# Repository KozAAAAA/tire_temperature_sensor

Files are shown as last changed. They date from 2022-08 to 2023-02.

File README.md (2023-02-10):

# Tire Temperature Sensor v2.0

**TTS** (Tire Temperature Sensor) is a PCB designed to measure temperature quickly, at a distance, and without the need to touch the wheels. The 4x16 pixel IR camera is used to obtain the data. It communicates with the STM microprocessor via the I2C protocol. Data is then averaged out to a 1x8 array of unsigned ints and sent with the CAN Transceiver to the car’s CAN network. This array can be then read off of the telemetry system implemented in the PM-08 racing car.

<p align="center">
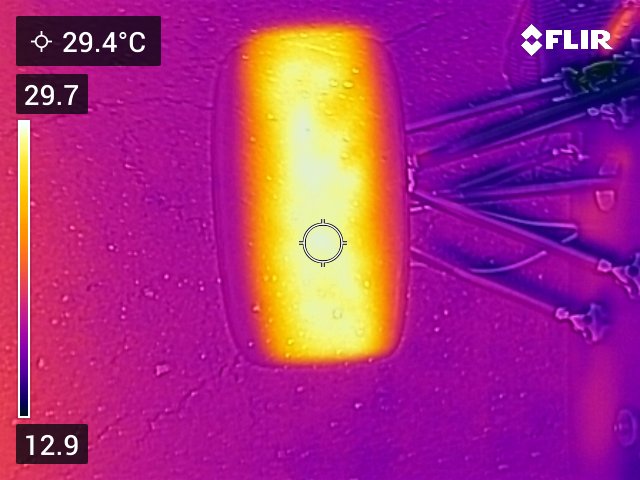
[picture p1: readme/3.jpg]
  
</p>

<p align="center">
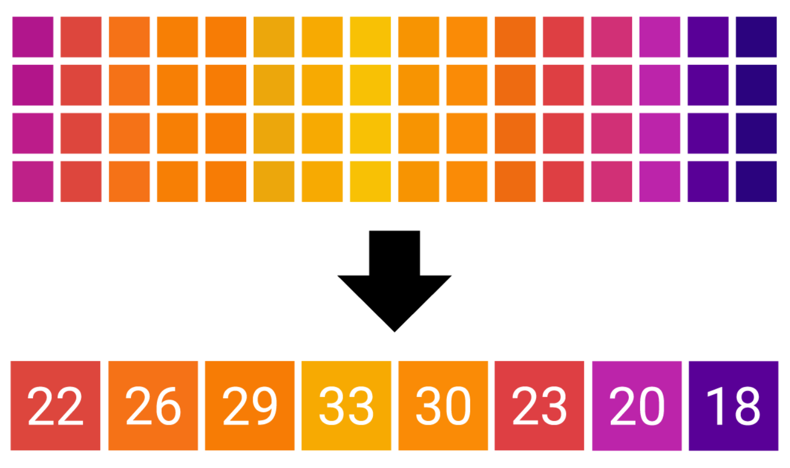
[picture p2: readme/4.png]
  
</p>

## Applications

While driving, a tire heats up. Heat dissipates differently across its surface and its rate changes depending on many factors (E.g. weather conditions or reoccurring acceleration). As a tire has its maximal temperature, exceeding this value may weaken its structural strength and cause its destruction in the worst-case scenario. This IR Camera PCB makes it possible to monitor a tire across its whole surface and prevent any damage associated with the temperature. As TTS monitors every wheel out of 4, our crew can easily detect if tires wear unevenly or excessively. Tire temperature patterns inform whether the car is properly calibrated, as the out-of-tune suspension causes tires to heat up significantly faster. This may result in grip loss in these areas.

## Core features

* 4x16 pixel MLX90621 thermal camera
* STM32L4P5RET
* 24V to 3.3V buck converter
* 3.3V to 2.6V LDO
* 3.3V CAN transceiver
* Overcurrent and reverse polarity protection
* Status LEDs

## PCB

<p align="center">
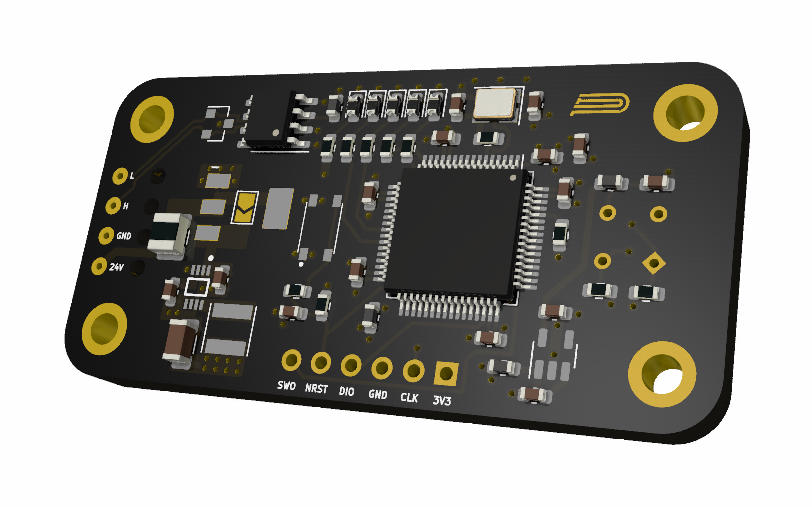
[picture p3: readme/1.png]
  
</p>
<p align="center">
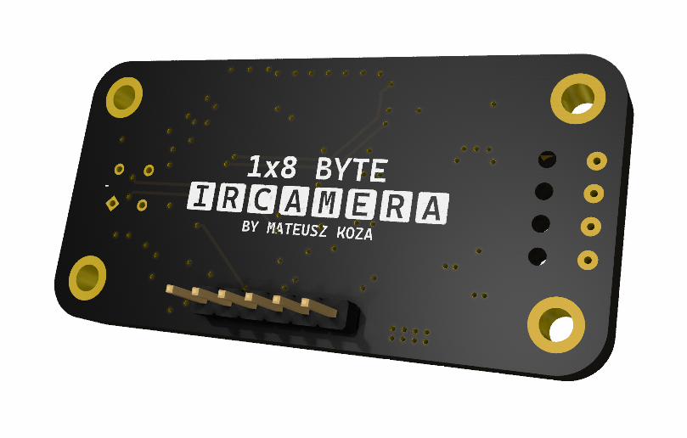
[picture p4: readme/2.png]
  
</p>

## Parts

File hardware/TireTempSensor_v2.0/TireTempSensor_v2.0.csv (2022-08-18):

Source: | /home/mateusz/Desktop/TireTempSensor_v2.0/hardware/TireTempSensor_v2.0/TireTempSensor_v2.0.kicad_sch
Date: | Wed 17 Aug 2022 20:23:14 CEST
Tool: | Eeschema 6.0.7-f9a2dced07~116~ubuntu20.04.1
Generator: | /usr/share/kicad/plugins/bom_csv_grouped_by_value_with_fp.py
Component Count: | 54
Ref | Qnty | Value | Cmp name | Footprint | Description | Vendor
C1, | 1 | 4u7 | C_Small | Capacitor_SMD:C_0603_1608Metric | Unpolarized capacitor, small symbol
C2, C3, C4, C5, C6, C7, C11, C14, C15, C17, | 10 | 100n | C | Capacitor_SMD:C_0603_1608Metric | Unpolarized capacitor
C9, C10, | 2 | 8p | C_Small | Capacitor_SMD:C_0603_1608Metric | Unpolarized capacitor, small symbol
C12, C13, | 2 | 1u | C | Capacitor_SMD:C_0603_1608Metric | Unpolarized capacitor
C16, | 1 | 10u | C | Capacitor_SMD:C_1206_3216Metric | Unpolarized capacitor
D1, | 1 | PESD2CAN,215 | NUP2105L | Package_TO_SOT_SMD:SOT-23 | Dual Line CAN Bus Protector, 24Vrwm
D2, D6, | 2 | RED | D_Small | Diode_SMD:D_0603_1608Metric | Diode, small symbol
D3, D4, | 2 | YELLOW | D_Small | Diode_SMD:D_0603_1608Metric | Diode, small symbol
D5, | 1 | GREEN | D_Small | Diode_SMD:D_0603_1608Metric | Diode, small symbol
F1, | 1 | 200mA | Polyfuse | Capacitor_SMD:C_1206_3216Metric | Resettable fuse, polymeric positive temperature coefficient
FB1, FB2, FB3, FB4, | 4 | 60R@100MHz | FerriteBead_Small | Inductor_SMD:L_0603_1608Metric | Ferrite bead, small symbol
H1, H2, H3, H4, | 4 | Mounting_Pad | MountingHole_Pad | MountingHole:MountingHole_2.7mm_M2.5_ISO14580_Pad | Mounting Hole with connection
IC1, | 1 | MAX15462AATA+ | MAX15462AATA+ | BuckSyncLib:SON50P300X200X80-8N | IC REG BUCK 3.3V 300MA 8TDFN
IC2, | 1 | MLX90621ESF-BAB-000-SP | MLX90621ESF-BAB-000-SP | IRSensor:MLX90621ESFBAB000SP | Board Mount Temperature Sensors 16X4 thermal array sensor, 3Volt, 60deg total FOV
J1, | 1 | SWD_01x06 | Conn_01x06 | Connector_PinHeader_2.54mm:PinHeader_1x06_P2.54mm_Vertical | Generic connector, single row, 01x06, script generated (kicad-library-utils/schlib/autogen/connector/)
J2, | 1 | CAN_01x04 | Conn_01x04 | Connector_Wire:SolderWire-0.1sqmm_1x04_P3.6mm_D0.4mm_OD1mm_Relief | Generic connector, single row, 01x04, script generated (kicad-library-utils/schlib/autogen/connector/)
JP1, | 1 | SolderJumper_2_Open | SolderJumper_2_Open | Jumper:SolderJumper-2_P1.3mm_Open_TrianglePad1.0x1.5mm | Solder Jumper, 2-pole, open
L1, | 1 | 33μH | L | Inductor_SMD:L_Vishay_IFSC-1515AH_4x4x1.8mm | Inductor
Q1, | 1 | FQT3P20TF | Q_PMOS_DSG | Mosfet:SOT-223-4-NFET | P-MOSFET transistor, drain/source/gate
R1, | 1 | 100k | R_Small_US | Resistor_SMD:R_0603_1608Metric | Resistor, small US symbol
R2, | 1 | 47 | R_Small_US | Resistor_SMD:R_0603_1608Metric | Resistor, small US symbol
R3, | 1 | 1k | R_Small_US | Resistor_SMD:R_0603_1608Metric | Resistor, small US symbol
R4, R7, R8, R9, R10, | 5 | 1k5 | R_Small_US | Resistor_SMD:R_0603_1608Metric | Resistor, small US symbol
R5, R6, | 2 | 4k7 | R_US | Resistor_SMD:R_0603_1608Metric | Resistor, US symbol
R11, | 1 | 10k | R_Small_US | Resistor_SMD:R_0603_1608Metric | Resistor, small US symbol
SW1, | 1 | RESET | SW_MEC_5G | Button:PTS815SJK250SMTRLFS | MEC 5G single pole normally-open tactile switch
U1, | 1 | STM32L4P5RET6 | STM32L4P5RET6 | Package_QFP:LQFP-64_10x10mm_P0.5mm
U2, | 1 | MIC5306-2.6YD5-TR | AP2112K-3.3 | Package_TO_SOT_SMD:SOT-23-5 | 600mA low dropout linear regulator, with enable pin, 3.8V-6V input voltage range, 3.3V fixed positive output, SOT-23-5
U3, | 1 | SN65HVD232 | SN65HVD232 | Package_SO:SOIC-8_3.9x4.9mm_P1.27mm | CAN Bus Transceivers, 3.3V, 1Mbps, SOIC-8
Y1, | 1 | 16MGHz | Crystal_GND24_Small | Crystal:Crystal_SMD_SeikoEpson_TSX3225-4Pin_3.2x2.5mm | Four pin crystal, GND on pins 2 and 4, small symbol

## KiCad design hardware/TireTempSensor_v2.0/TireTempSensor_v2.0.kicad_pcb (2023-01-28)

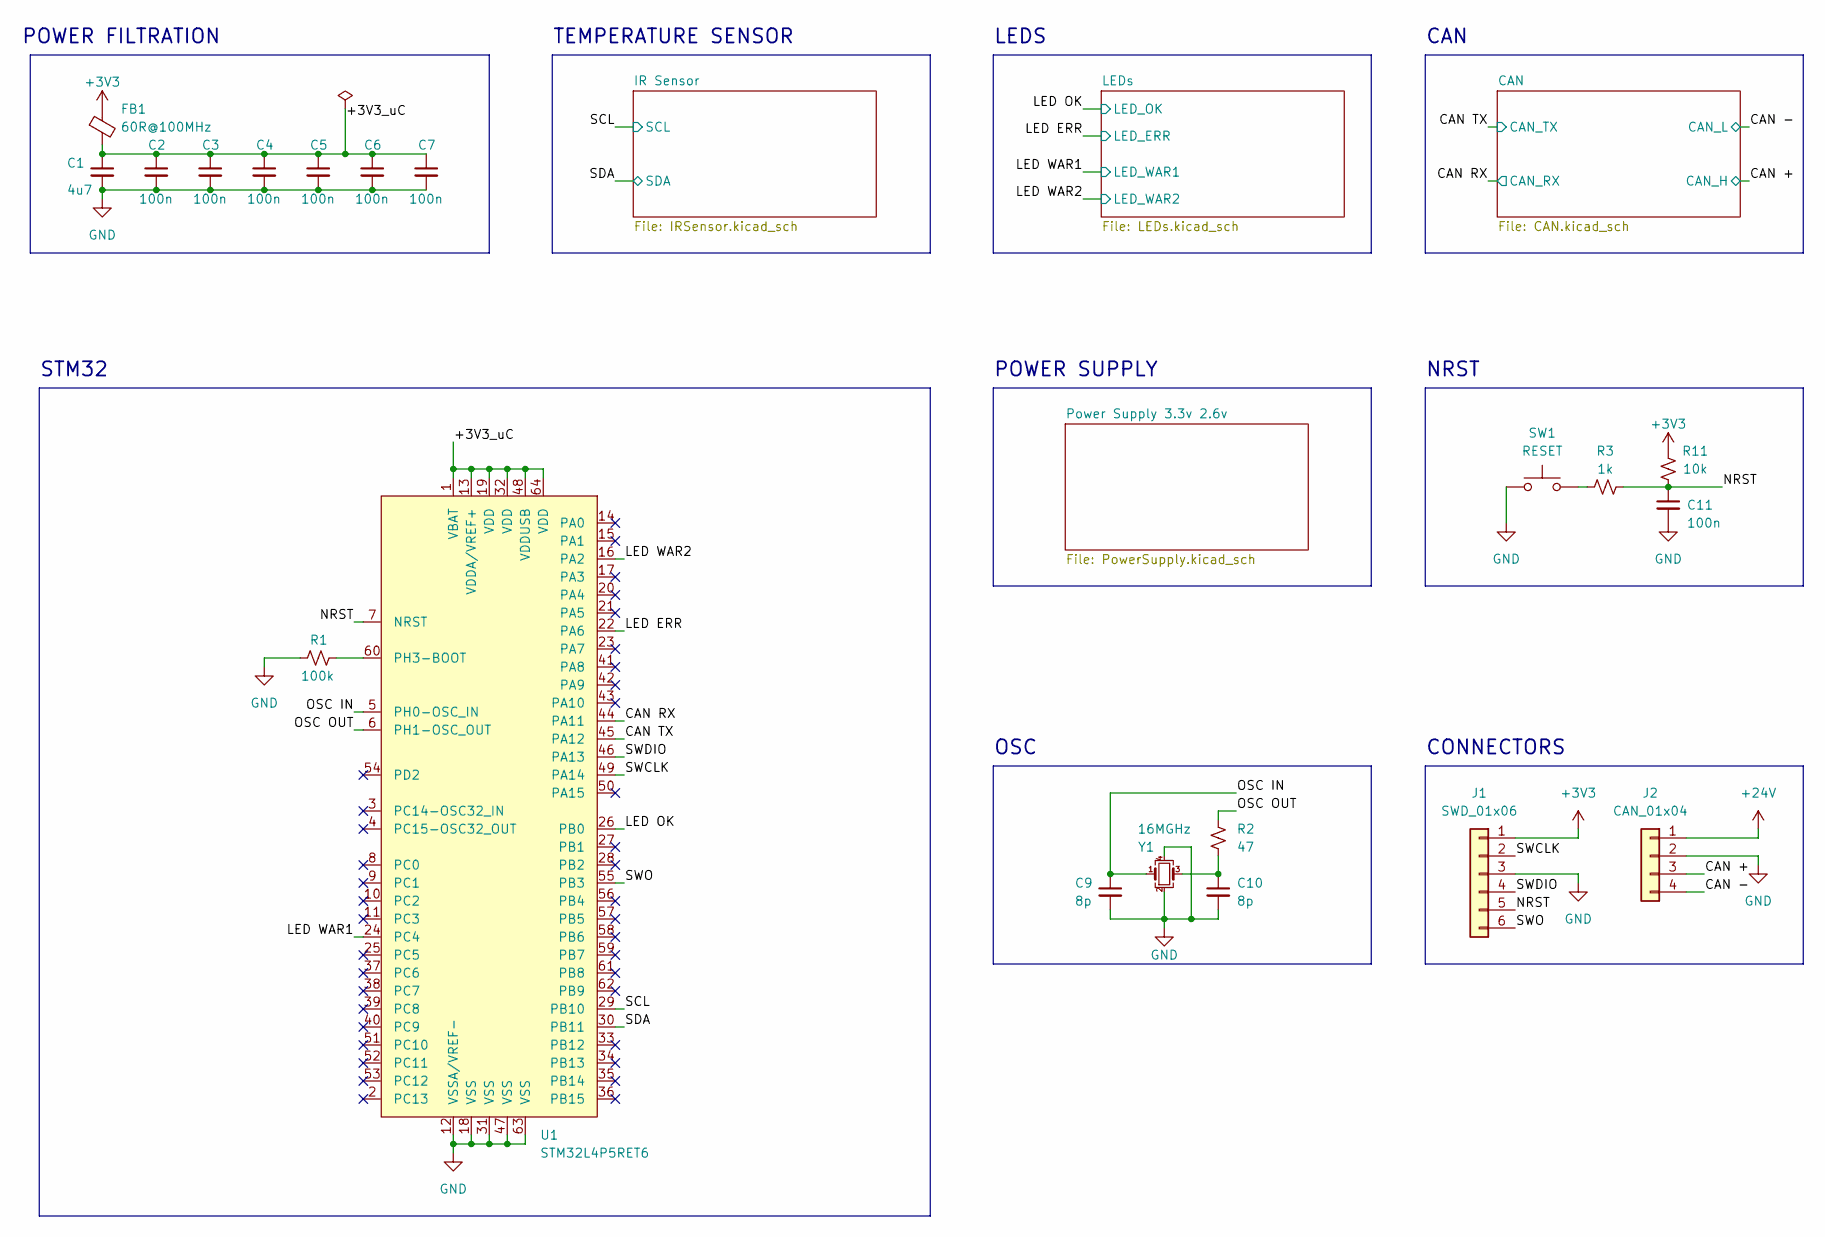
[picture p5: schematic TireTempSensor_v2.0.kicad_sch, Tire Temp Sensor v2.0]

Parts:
C1: 4u7; C_0603_1608Metric
C2, C3, C4, C5, C6, C7, C11: 100n; C_0603_1608Metric
C9, C10: 8p; C_0603_1608Metric
FB1: 60R@100MHz; L_0603_1608Metric
J1: SWD_01x06; PinHeader_1x06_P2.54mm_Vertical
J2: CAN_01x04; SolderWire-0.1sqmm_1x04_P3.6mm_D0.4mm_OD1mm_Relief
R1: 100k; R_0603_1608Metric
R2: 47; R_0603_1608Metric
R3: 1k; R_0603_1608Metric
R11: 10k; R_0603_1608Metric
SW1: RESET; PTS815SJK250SMTRLFS
U1: STM32L4P5RET6; LQFP-64_10x10mm_P0.5mm
Y1: 16MGHz; Crystal_SMD_SeikoEpson_TSX3225-4Pin_3.2x2.5mm

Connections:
+3V3: FB1.1, J1.1, R11.2; also elsewhere on the board
+24V: J2.1; also elsewhere on the board
/+3V3_uC: C1.1, C2.1, C3.1, C4.1, C5.1, C6.1, C7.1, FB1.2, U1.1 (VBAT), U1.13 (VDDA/VREF+), U1.19 (VDD), U1.32 (VDD), U1.48 (VDDUSB), U1.64 (VDD)
/CAN +: J2.3; also elsewhere on the board
/CAN -: J2.4; also elsewhere on the board
/CAN RX: U1.44 (PA11); also elsewhere on the board
/CAN TX: U1.45 (PA12); also elsewhere on the board
/LED ERR: U1.22 (PA6); also elsewhere on the board
/LED OK: U1.26 (PB0); also elsewhere on the board
/LED WAR1: U1.24 (PC4); also elsewhere on the board
/LED WAR2: U1.16 (PA2); also elsewhere on the board
/NRST: C11.1, J1.5, R3.2, R11.1, U1.7 (NRST)
/OSC IN: C9.1, U1.5 (PH0-OSC_IN), Y1.1
/OSC OUT: R2.1, U1.6 (PH1-OSC_OUT)
/SCL: U1.29 (PB10); also elsewhere on the board
/SDA: U1.30 (PB11); also elsewhere on the board
/SWCLK: J1.2, U1.49 (PA14)
/SWDIO: J1.4, U1.46 (PA13)
/SWO: J1.6, U1.55 (PB3)
GND: C1.2, C2.2, C3.2, C4.2, C5.2, C6.2, C7.2, C9.2, C10.2, C11.2, J1.3, J2.2, R1.2, SW1.1 (A), SW1.2 (A), U1.12 (VSSA/VREF-), U1.18 (VSS), U1.31 (VSS), U1.47 (VSS), U1.63 (VSS), Y1.2, Y1.4; also elsewhere on the board
unnamed: C10.1, R2.2, Y1.3
unnamed: R1.1, U1.60 (PH3-BOOT)
unnamed: R3.1, SW1.3 (B), SW1.4 (B)

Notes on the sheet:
NRST
POWER SUPPLY
OSC
STM32
CAN
POWER FILTRATION
LEDS
CONNECTORS
TEMPERATURE SENSOR

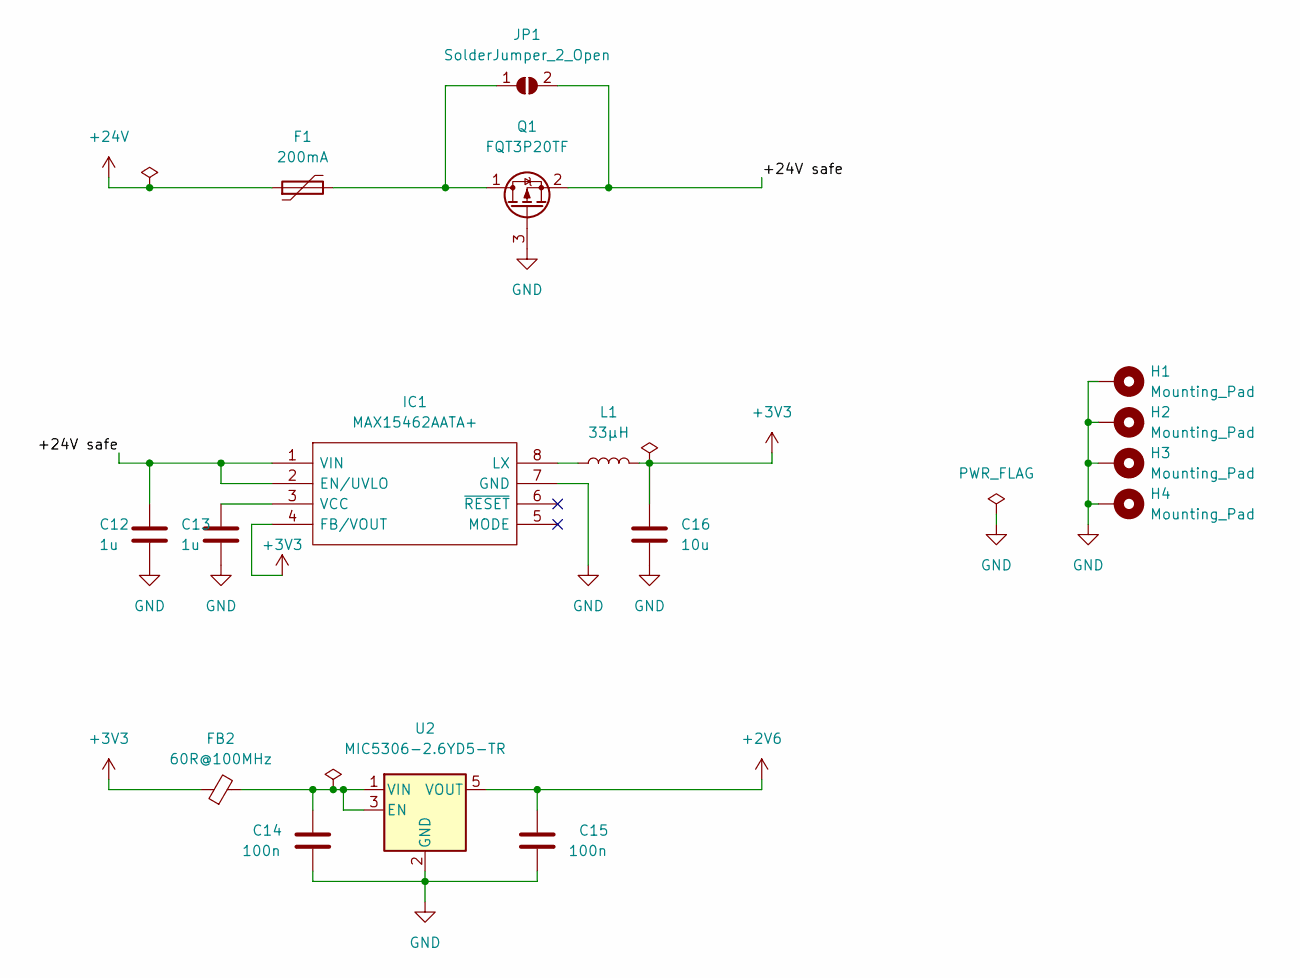
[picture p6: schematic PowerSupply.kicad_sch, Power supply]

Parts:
C12, C13: 1u; C_0603_1608Metric
C14, C15: 100n; C_0603_1608Metric
C16: 10u; C_1206_3216Metric
F1: 200mA; Fuse_1210_3225Metric
FB2: 60R@100MHz; L_0603_1608Metric
H1, H2, H3, H4: Mounting_Pad; MountingHole_2.7mm_M2.5_ISO14580_Pad
IC1: MAX15462AATA+; TDFN-8-1EP_2x2mm_P0.5mm_EP0.8x1.2mm; Manufacturer_Part_Number MAX15462AATA+; Mouser Part Number 700-MAX15462AATA+
JP1: SolderJumper_2_Open; SolderJumper-2_P1.3mm_Open_TrianglePad1.0x1.5mm
L1: 33μH; L_Vishay_IFSC-1515AH_4x4x1.8mm
Q1: FQT3P20TF; SOT-223-4-NFET
U2: MIC5306-2.6YD5-TR; SOT-23-5

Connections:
+2V6: C15.1, U2.5 (VOUT); also elsewhere on the board
+3V3: C16.1, FB2.1, IC1.4 (FB/VOUT), L1.2; also elsewhere on the board
+24V: F1.1; also elsewhere on the board
/Power Supply 3.3v 2.6v/+24V safe: C12.1, IC1.1 (VIN), IC1.2 (EN/UVLO), JP1.2 (B), Q1.2 (S)
GND: C12.2, C13.2, C14.2, C15.2, C16.2, H1.1, H2.1, H3.1, H4.1, IC1.7 (GND), Q1.3 (G), U2.2 (GND); also elsewhere on the board
unnamed: C13.1, IC1.3 (VCC)
unnamed: C14.1, FB2.2, U2.1 (VIN), U2.3 (EN)
unnamed: F1.2, JP1.1 (A), Q1.1 (D)
unnamed: IC1.8 (LX), L1.1

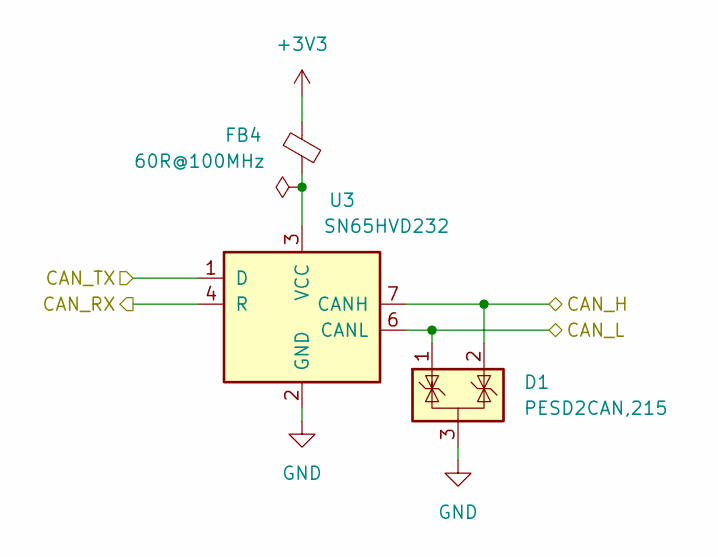
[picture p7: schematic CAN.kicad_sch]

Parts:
D1: PESD2CAN,215; SOT-23
FB4: 60R@100MHz; L_0603_1608Metric
U3: SN65HVD232; SOIC-8_3.9x4.9mm_P1.27mm

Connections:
+3V3: FB4.1; also elsewhere on the board
/CAN +: D1.2 (K), U3.7 (CANH); also elsewhere on the board
/CAN -: D1.1 (K), U3.6 (CANL); also elsewhere on the board
/CAN RX: U3.4 (R); also elsewhere on the board
/CAN TX: U3.1 (D); also elsewhere on the board
GND: D1.3 (A), U3.2 (GND); also elsewhere on the board
unnamed: FB4.2, U3.3 (VCC)

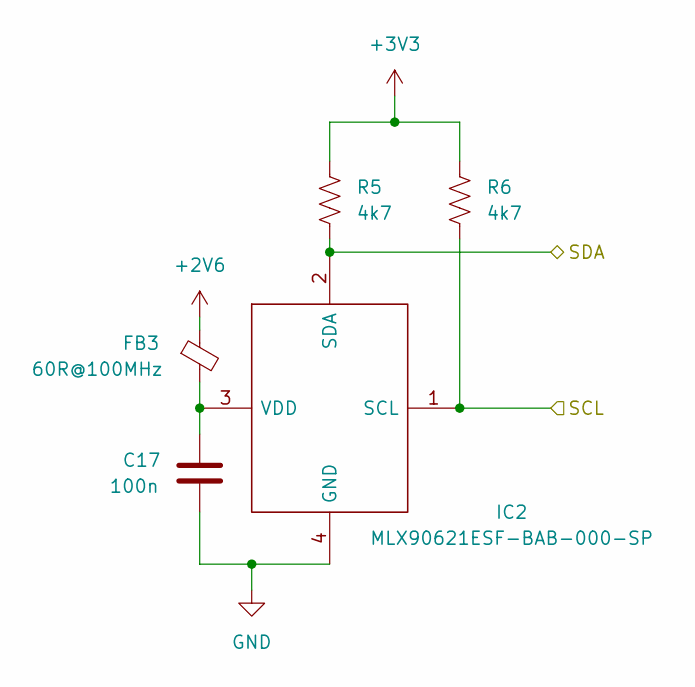
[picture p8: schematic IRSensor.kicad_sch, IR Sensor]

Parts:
C17: 100n; C_0603_1608Metric
FB3: 60R@100MHz; L_0603_1608Metric
IC2: MLX90621ESF-BAB-000-SP; MLX90621ESFBAB000SP; Manufacturer_Part_Number MLX90621ESF-BAB-000-SP; Mouser Part Number 482-90621ESFBAB000SP
R5, R6: 4k7; R_0603_1608Metric

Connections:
+2V6: FB3.1; also elsewhere on the board
+3V3: R5.1, R6.1; also elsewhere on the board
/SCL: IC2.1 (SCL), R6.2; also elsewhere on the board
/SDA: IC2.2 (SDA), R5.2; also elsewhere on the board
GND: C17.2, IC2.4 (GND); also elsewhere on the board
unnamed: C17.1, FB3.2, IC2.3 (VDD)

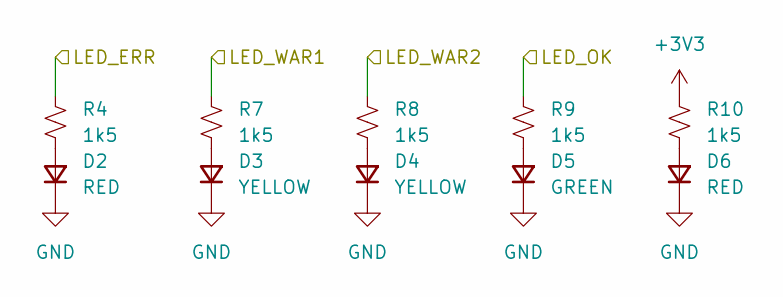
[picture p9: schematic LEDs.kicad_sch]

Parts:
D2, D6: RED; D_0603_1608Metric
D3, D4: YELLOW; D_0603_1608Metric
D5: GREEN; D_0603_1608Metric
R4, R7, R8, R9, R10: 1k5; R_0603_1608Metric

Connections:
+3V3: R10.1; also elsewhere on the board
/LED ERR: R4.1; also elsewhere on the board
/LED OK: R9.1; also elsewhere on the board
/LED WAR1: R7.1; also elsewhere on the board
/LED WAR2: R8.1; also elsewhere on the board
GND: D2.1 (K), D3.1 (K), D4.1 (K), D5.1 (K), D6.1 (K); also elsewhere on the board
unnamed: D2.2 (A), R4.2
unnamed: D3.2 (A), R7.2
unnamed: D4.2 (A), R8.2
unnamed: D5.2 (A), R9.2
unnamed: D6.2 (A), R10.2

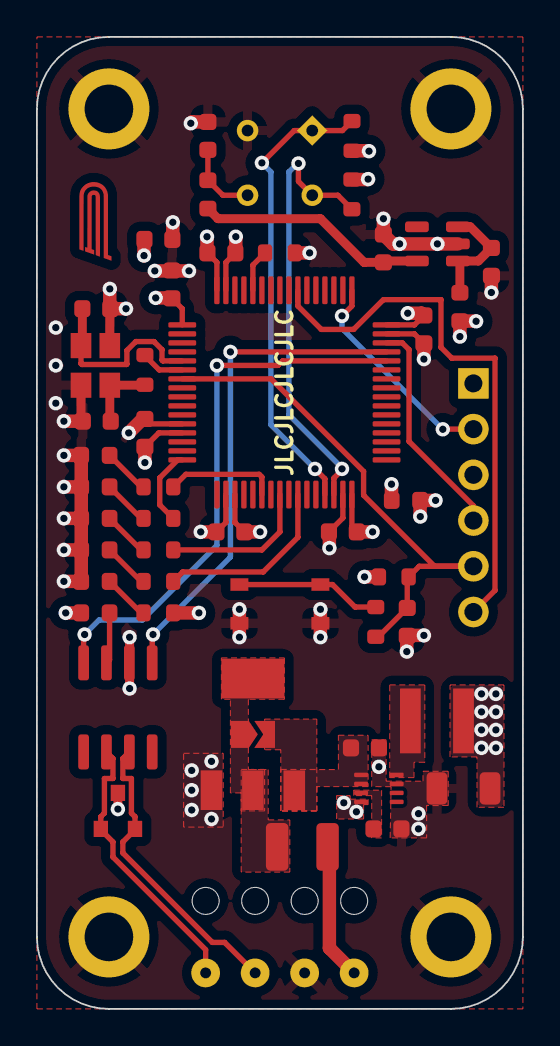
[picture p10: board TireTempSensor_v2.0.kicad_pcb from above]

Board: 4 copper layers, 27.0 x 54.0 mm, 54 parts (1 on the bottom side), 36 nets.

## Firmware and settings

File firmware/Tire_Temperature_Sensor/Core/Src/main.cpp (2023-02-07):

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
/* Includes ------------------------------------------------------------------*/
#include "main.h"
#include "can.h"
#include "i2c.h"
#include "tim.h"
#include "gpio.h"

/* USER CODE BEGIN Includes */

#include "MLX90621_API.h"
#include "MLX90621_I2C_Driver.h"
#include "can_interface.hpp"

/* USER CODE END Includes */


/* USER CODE BEGIN PV */

static constexpr float emissivity = 0.98f;
static constexpr float tr = 15.0f;

static volatile bool mlx_receive_flag = true;
static volatile bool process_and_send_flag = false;

static uint8_t mlx90621ToAverage[8] = {0};
static uint8_t eeMLX90621[256];
static paramsMLX90621 mlx90621;
static uint16_t mlx90621Frame[66];
static float mlx90621To[64];

/* USER CODE END PV */


void SystemClock_Config(void);

/* USER CODE BEGIN 0 */

static void led_reset(){
	HAL_GPIO_WritePin(LED_OK_GPIO_Port, LED_OK_Pin, GPIO_PIN_RESET);
	HAL_GPIO_WritePin(LED_WAR1_GPIO_Port, LED_WAR1_Pin, GPIO_PIN_RESET);
	HAL_GPIO_WritePin(LED_WAR2_GPIO_Port, LED_WAR2_Pin, GPIO_PIN_RESET);
	HAL_GPIO_WritePin(LED_ERR_GPIO_Port, LED_ERR_Pin, GPIO_PIN_RESET);
}

static void mlx_receive()
{
	if(MLX90621_GetFrameData(mlx90621Frame) != HAL_OK){
		  HAL_GPIO_WritePin(LED_ERR_GPIO_Port, LED_ERR_Pin, GPIO_PIN_SET);
		  return;
	}
}

static void process_and_send()
{
	MLX90621_I2C_Seq_Interpret_Data();
	MLX90621_CalculateTo(mlx90621Frame, &mlx90621, emissivity, tr, mlx90621To);
	if(MLX90621_AverageTo(mlx90621To, mlx90621ToAverage)){
		HAL_GPIO_WritePin(LED_WAR2_GPIO_Port, LED_WAR2_Pin, GPIO_PIN_SET);
	}

	PUTM_CAN::WheelTemp_main ttsMessage{
		  .wheelTemp = {
				  mlx90621ToAverage[0],
				  mlx90621ToAverage[1],
				  mlx90621ToAverage[2],
				  mlx90621ToAverage[3],
				  mlx90621ToAverage[4],
				  mlx90621ToAverage[5],
				  mlx90621ToAverage[6],
				  mlx90621ToAverage[7]
		  }
	};
	auto ttsMainFrame = PUTM_CAN::Can_tx_message<PUTM_CAN::WheelTemp_main>(ttsMessage, PUTM_CAN::can_tx_header_WHEELTEMP_MAIN);

	if(ttsMainFrame.send(hcan1) != HAL_OK){
		  HAL_GPIO_WritePin(LED_ERR_GPIO_Port, LED_ERR_Pin, GPIO_PIN_SET);
	}
	else{
		  HAL_GPIO_WritePin(LED_OK_GPIO_Port, LED_OK_Pin, GPIO_PIN_SET);
	}
}

/* USER CODE END 0 */

/**
  * @brief  The application entry point.
  * @retval int
  */

int main(void)
{
  /* MCU Configuration--------------------------------------------------------*/

  /* Reset of all peripherals, Initializes the Flash interface and the Systick. */

  HAL_Init();

  /* Configure the system clock */
  SystemClock_Config();

  /* Initialize all configured peripherals */
  MX_GPIO_Init();
  MX_CAN1_Init();
  MX_I2C2_Init();
  MX_TIM1_Init();

  /* USER CODE BEGIN 2 */

  if(HAL_CAN_Start(&hcan1) != HAL_OK ||
     HAL_CAN_ActivateNotification(&hcan1, CAN_IT_RX_FIFO0_MSG_PENDING) != HAL_OK ||
     MLX90621_DumpEE(eeMLX90621)!= HAL_OK ||
	 MLX90621_Configure(eeMLX90621) != HAL_OK ||
	 MLX90621_ExtractParameters(eeMLX90621, &mlx90621) != HAL_OK ||
	 HAL_TIM_Base_Start_IT(&htim1) != HAL_OK)
  {
	  HAL_GPIO_WritePin(LED_ERR_GPIO_Port, LED_ERR_Pin, GPIO_PIN_SET);
	  return HAL_ERROR;
  }

  /* USER CODE END 2 */

  /* Infinite loop */
  /* USER CODE BEGIN WHILE */
  while (1){

	  if(mlx_receive_flag == true){
		  led_reset();
		  mlx_receive();
		  mlx_receive_flag = false;
	  }

	  if(process_and_send_flag == true){
		  process_and_send();
		  process_and_send_flag = false;
	  }

    /* USER CODE END WHILE */

	/* USER CODE BEGIN 3 */
  }
  /* USER CODE END 3 */
}

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
/* USER CODE BEGIN 4 */

void HAL_TIM_PeriodElapsedCallback(TIM_HandleTypeDef *htim)
{
  if (htim == &htim1)
  {
	  mlx_receive_flag = true;
  }
}

void HAL_I2C_MasterTxCpltCallback (I2C_HandleTypeDef * hi2c)
{
	if(MLX90621_I2C_Seq_Receive_IT() != HAL_OK){
		HAL_GPIO_WritePin(LED_ERR_GPIO_Port, LED_ERR_Pin, GPIO_PIN_SET);
	}
}

void HAL_I2C_MasterRxCpltCallback (I2C_HandleTypeDef * hi2c)
{
	process_and_send_flag = true;
}

/* USER CODE END 4 */
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


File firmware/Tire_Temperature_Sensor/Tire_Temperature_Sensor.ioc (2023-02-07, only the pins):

Mcu.UserName=STM32L4P5RETx
PA11.Signal=CAN1_RX
PA12.Signal=CAN1_TX
PA2.GPIO_Label=LED_WAR2
PA2.Signal=GPIO_Output
PA6.GPIO_Label=LED_ERR
PA6.Signal=GPIO_Output
PB0.GPIO_Label=LED_OK
PB0.Signal=GPIO_Output
PB10.Signal=I2C2_SCL
PB11.Signal=I2C2_SDA
PC4.GPIO_Label=LED_WAR1
PC4.Signal=GPIO_Output

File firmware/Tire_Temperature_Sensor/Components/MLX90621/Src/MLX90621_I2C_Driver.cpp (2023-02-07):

/**
 * @copyright (C) 2017 Melexis N.V.
 *
 * Licensed under the Apache License, Version 2.0 (the "License");
 * you may not use this file except in compliance with the License.
 * You may obtain a copy of the License at
 *
 *     http://www.apache.org/licenses/LICENSE-2.0
 *
 * Unless required by applicable law or agreed to in writing, software
 * distributed under the License is distributed on an "AS IS" BASIS,
 * WITHOUT WARRANTIES OR CONDITIONS OF ANY KIND, either express or implied.
 * See the License for the specific language governing permissions and
 * limitations under the License.
 *
 */


#include "MLX90621_I2C_Driver.h"
#include "i2c.h"


static uint8_t seq_slaveAddr;
static uint8_t seq_nMemAddressRead;
static uint16_t *seq_data = NULL;
static uint8_t seq_i2cData[132] = {0};

int MLX90621_I2CRead(uint8_t slaveAddr,uint8_t command, uint8_t startAddress, uint8_t addressStep, uint8_t nMemAddressRead, uint16_t *data)
{
	seq_slaveAddr = slaveAddr;
	seq_nMemAddressRead = nMemAddressRead;
	seq_data = data;

    uint8_t cmd[4] = {0,0,0,0};

    cmd[0] = command;
    cmd[1] = startAddress;
    cmd[2] = addressStep;
    cmd[3] = nMemAddressRead;

    if(HAL_I2C_Master_Seq_Transmit_IT(&hi2c2, (seq_slaveAddr << 1), cmd, 4, I2C_FIRST_FRAME) != HAL_OK)
    {
    	return -1;
    }

    return 0;
}

int MLX90621_I2C_Seq_Receive_IT(){
	return HAL_I2C_Master_Seq_Receive_IT(&hi2c2, (seq_slaveAddr<<1), seq_i2cData, 2*seq_nMemAddressRead, I2C_LAST_FRAME);
}

void MLX90621_I2C_Seq_Interpret_Data()
{
	int i = 0;
	int cnt=0;

    for(cnt=0; cnt < seq_nMemAddressRead; cnt++)
    {
        i = cnt << 1;
        *seq_data++ = (uint16_t)seq_i2cData[i+1]*256 + (uint16_t)seq_i2cData[i];
    }
}

void MLX90621_I2CInit(){
	// .ioc
}

void MLX90621_I2CFreqSet(int freq){
	// .ioc
}

int MLX90621_I2CReadEEPROM(uint8_t slaveAddr, uint8_t startAddress, uint16_t nMemAddressRead, uint8_t *data)
{
    int cnt = 0;
    uint8_t i2cData[256] = {0};
    
    if(HAL_I2C_Mem_Read(&hi2c2, (slaveAddr << 1), startAddress, 1, i2cData, nMemAddressRead, 100) != HAL_OK)
    {
    	return -1;
    }
    
    for(cnt=0; cnt < nMemAddressRead; cnt++)
    {
        *data++ = i2cData[cnt];
    }

    return 0;
} 


static int MLX90621_I2CRead_Polling(uint8_t slaveAddr,uint8_t command, uint8_t startAddress, uint8_t addressStep, uint8_t nMemAddressRead, uint16_t *data)
{
    int cnt = 0;
    int i = 0;
    uint8_t i2cData[132] = {0};


    if(Custom_HAL_I2C_Mem_Read(&hi2c2, (slaveAddr << 1), command, startAddress, addressStep, nMemAddressRead, i2cData, 2*nMemAddressRead, 100) != HAL_OK)
    {
    	return -1;
    }

    for(cnt=0; cnt < nMemAddressRead; cnt++)
    {
        i = cnt << 1;
        *data++ = (uint16_t)i2cData[i+1]*256 + (uint16_t)i2cData[i];
    }

    return 0;
} 

int MLX90621_I2CWrite(uint8_t slaveAddr, uint8_t command, uint8_t checkValue, uint16_t data)
{
    uint8_t cmd[5] = {0,0,0,0,0};
    static uint16_t dataCheck;
    
    cmd[0] = command;
    cmd[2] = data & 0x00FF;
    cmd[1] = cmd[2] - checkValue;
    cmd[4] = data >> 8;
    cmd[3] = cmd[4] - checkValue;

    if(HAL_I2C_Master_Transmit(&hi2c2, (slaveAddr << 1), cmd, 5, 100) != HAL_OK)
    {
        return -1;
    }

    MLX90621_I2CRead_Polling(slaveAddr, 0x02, 0x8F+command, 0, 1, &dataCheck);
    
    if (dataCheck != data)
    {
        return -2;
    }    
    
    return 0;
}

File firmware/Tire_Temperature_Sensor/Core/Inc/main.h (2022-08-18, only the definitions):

#define LED_WAR2_Pin GPIO_PIN_2
#define LED_WAR2_GPIO_Port GPIOA
#define LED_ERR_Pin GPIO_PIN_6
#define LED_ERR_GPIO_Port GPIOA
#define LED_WAR1_Pin GPIO_PIN_4
#define LED_WAR1_GPIO_Port GPIOC
#define LED_OK_Pin GPIO_PIN_0
#define LED_OK_GPIO_Port GPIOB

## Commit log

2022-08-15 buck & reversed bias protection
    [CAN.kicad_sch, IRSensor.kicad_sch, LEDs.kicad_sch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]
2022-08-15 PFET & buck caps models
    [CAN.kicad_sch, IRSensor.kicad_sch, LEDs.kicad_sch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]
2022-08-16 stm selection & pin assignment
2022-08-16 schematic complete
    [TireTempSensor_v2.0.kicad_sch]
2022-08-16 erc tests passed
    [CAN.kicad_sch, IRSensor.kicad_sch, LEDs.kicad_sch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]
2022-08-16 changed the stm
    [PowerSupply.kicad_sch, TireTempSensor_v2.0.kicad_sch]
2022-08-17 footprints added
2022-08-17 rough pcb layout
    [CAN.kicad_sch, PowerSupply.kicad_sch, TireTempSensor_v2.0.kicad_pcb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]
2022-08-18 some pcb connections
    [PowerSupply.kicad_sch, TireTempSensor_v2.0.csv, TireTempSensor_v2.0.kicad_pcb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]
2022-08-18 more pcb connections
    [TireTempSensor_v2.0.kicad_pcb, TireTempSensor_v2.0.kicad_sch]
2022-08-18 gnd vias added
    [TireTempSensor_v2.0.kicad_pcb]
2022-08-19 silkscreen text added
    [TireTempSensor_v2.0.kicad_pcb]
2022-08-22 front silkscreen
    [TireTempSensor_v2.0.kicad_pcb]
2022-08-22 pcb is done
    [TireTempSensor_v2.0.kicad_pcb]
2022-10-21 footprint has been changed + some minor silkscreen changes
    [PowerSupply.kicad_sch, TireTempSensor_v2.0.kicad_pcb, TireTempSensor_v2.0.kicad_sch]
2022-11-16 Everything tested and works - code is garbage tho
    [TireTempSensor_v2.0-B_Cu.gbr, TireTempSensor_v2.0-B_Mask.gbr, TireTempSensor_v2.0-B_Paste.gbr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]
2023-01-28 Restructure code
    [TireTempSensor_v2.0.kicad_pcb]
2023-01-29 Add TIM1 as main loop, Raise an error in the form of the LED color
    [MLX90621_API.cpp, Tire_Temperature_Sensor.ioc, main.cpp]
2023-01-29 Fix bug LED OK when its not
    [main.cpp]
2023-02-04 Add flags in interrupts and check them in the infinite loop
2023-02-07 Add sequential IT communication, data bug tho
    [MLX90621_I2C_Driver.cpp, Tire_Temperature_Sensor.ioc, main.cpp]

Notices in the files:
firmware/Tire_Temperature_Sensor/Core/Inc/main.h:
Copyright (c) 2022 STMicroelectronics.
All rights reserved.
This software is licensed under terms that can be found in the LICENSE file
